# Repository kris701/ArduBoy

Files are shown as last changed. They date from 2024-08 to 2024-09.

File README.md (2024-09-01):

# ArduBoy

This is a project to make my own gameboy-like console, with its own scripting language and dynamic runtime on an Arduino.

Physically, its more or less equal to a Gameboy Pocket, except this one is a bit thicker and the screen is a bit smaller.
Other than that, it has the same button layout. 
Instead of using disposable batteries, it has a internal LiPo instead with a USB-C port for charging.
Games are semi-compiled into a easier to read format for the Arduino. The semi-compiled code is put on an SD card, that the ArduBoy can then parse and run.

In hindsight, it might have a bit of an overkill battery of 3000mAh, so it can technically run for a few days without a charge.

You can take a look in the [Games](./Games) folder for some already made games for the Arduino, or you can make some yourself!

You can use the CLI tool to compile the script file onto an SD card.
The tool will also do a bit of syntax checking to make sure there arent obvious errors in the script file.

## ArduBoy Script (`.abs`) Syntax

Generally the syntax of the ArduBoy Scripts are heavy encapsulation with `(` and `)`.
An example of this can be seen below:

```
(
	(:name Example)
	(:includes (:include core))

	(:func Setup
		(
			// Setup code goes here
			// This code only runs once
		)
	)

	(:func Loop
		(
			// Looping code goes here
			// The code in here will loop
		)
	)
)
```

## Parts

Here is a general list of the electronic parts that was used in this project.

* [3000 mAh battery](https://www.ebay.com/itm/121823784057)
* [USB-C Charging board](https://www.ebay.com/itm/325273541405)
* [SD card reader](https://www.ebay.com/itm/170895501953)
* [Arduino Nano](https://www.ebay.com/itm/364546971433?var=634055018693)
* [Button PCB](https://www.ebay.com/itm/296243650365?var=594299882127)
* [OLED Screen](https://www.ebay.com/itm/225810919466)
* [3.7v to 5v boster](https://www.ebay.com/itm/255301455926)

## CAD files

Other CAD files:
Fusion/ArduBoyBody.f3d

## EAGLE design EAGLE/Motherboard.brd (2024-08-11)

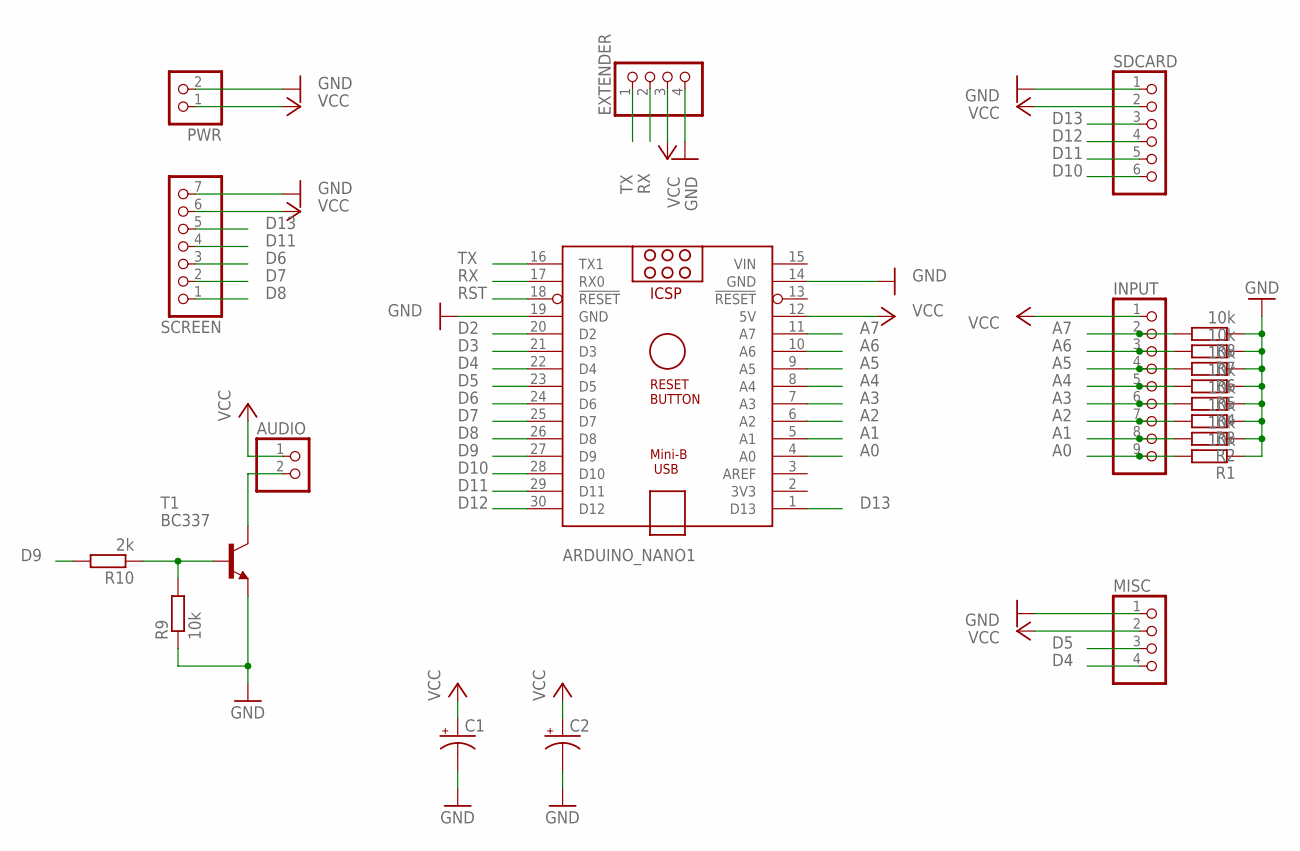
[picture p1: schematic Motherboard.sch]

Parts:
ARDUINO_NANO1: ARDUINO_NANO
AUDIO: PINHD-1X2; 1X02
C1, C2: CPOL-USE2.5-6; E2,5-6
EXTENDER: PINHD-1X4; 1X04
INPUT: PINHD-1X9; 1X09
MISC: PINHD-1X4; 1X04
PWR: PINHD-1X2; 1X02
R1, R2, R3, R4, R5, R6, R7, R8, R9: 10k; 0204/7
R10: 2k; 0204/7
SCREEN: PINHD-1X7; 1X07
SDCARD: PINHD-1X6; 1X06
T1: BC337; TO92

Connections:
A0: ARDUINO_NANO1.4 (A0), INPUT.9, R1.2
A1: ARDUINO_NANO1.5 (A1), INPUT.8, R2.2
A2: ARDUINO_NANO1.6 (A2), INPUT.7, R3.2
A3: ARDUINO_NANO1.7 (A3), INPUT.6, R4.2
A4: ARDUINO_NANO1.8 (A4), INPUT.5, R5.2
A5: ARDUINO_NANO1.9 (A5), INPUT.4, R6.2
A6: ARDUINO_NANO1.10 (A6), INPUT.3, R7.2
A7: ARDUINO_NANO1.11 (A7), INPUT.2, R8.2
D2: ARDUINO_NANO1.20 (D2)
D3: ARDUINO_NANO1.21 (D3)
D4: ARDUINO_NANO1.22 (D4), MISC.4
D5: ARDUINO_NANO1.23 (D5), MISC.3
D6: ARDUINO_NANO1.24 (D6), SCREEN.3
D7: ARDUINO_NANO1.25 (D7), SCREEN.2
D8: ARDUINO_NANO1.26 (D8), SCREEN.1
D9: ARDUINO_NANO1.27 (D9), R10.2
D10: ARDUINO_NANO1.28 (D10), SDCARD.6
D11: ARDUINO_NANO1.29 (D11), SCREEN.4, SDCARD.5
D12: ARDUINO_NANO1.30 (D12), SDCARD.4
D13: ARDUINO_NANO1.1 (D13), SCREEN.5, SDCARD.3
GND: ARDUINO_NANO1.14 (GND), ARDUINO_NANO1.19 (GND), C1.-, C2.-, EXTENDER.4, MISC.1, PWR.2, R1.1, R2.1, R3.1, R4.1, R5.1, R6.1, R7.1, R8.1, R9.1, SCREEN.7, SDCARD.1, T1.1 (E)
unnamed: AUDIO.2, T1.3 (C)
unnamed: R9.2, R10.1, T1.2 (B)
RST: ARDUINO_NANO1.18 (!RESET)
RX: ARDUINO_NANO1.17 (RX0), EXTENDER.2
TX: ARDUINO_NANO1.16 (TX1), EXTENDER.1
VCC: ARDUINO_NANO1.12 (5V), AUDIO.1, C1.+, C2.+, EXTENDER.3, INPUT.1, MISC.2, PWR.1, SCREEN.6, SDCARD.2
VIN: ARDUINO_NANO1.15 (VIN)

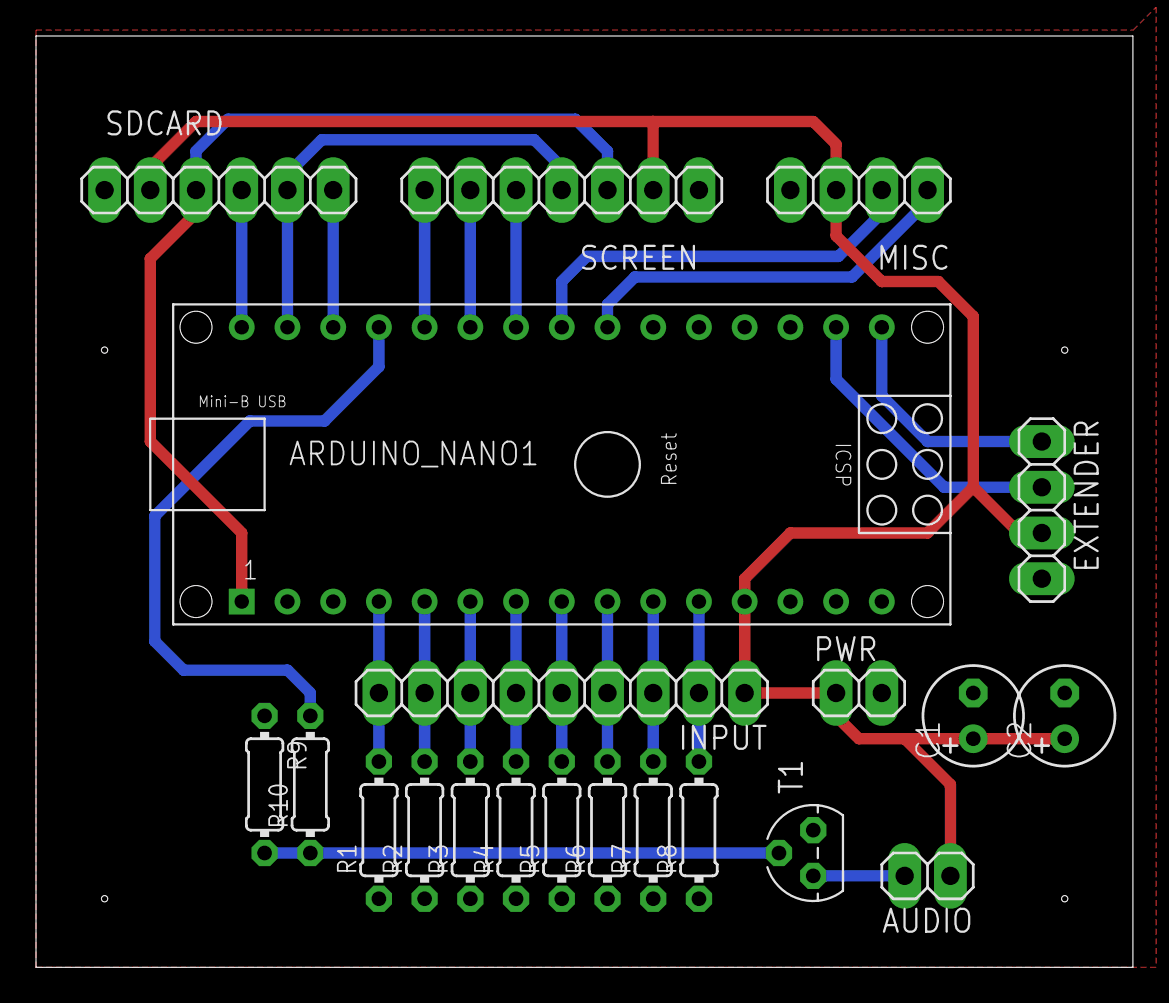
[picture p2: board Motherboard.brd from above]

Board: 2 copper layers, 60.9 x 51.7 mm, 21 parts (0 on the bottom side), 24 nets.

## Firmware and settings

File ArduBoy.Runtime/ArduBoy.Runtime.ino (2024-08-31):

#include <Adafruit_SSD1351.h>
#include <SPI.h>
#include <SD.h>

#define DEBUG

#define Audio_Pin               9
#define SD_CS                   10
#define SCREEN_CS               8
#define SCREEN_DC               7
#define SCREEN_RST              6
#define SCREEN_WIDTH            128
#define SCREEN_HEIGHT           128
#define INPUT_UP                A7
#define INPUT_DOWN              A4
#define INPUT_LEFT              A0
#define INPUT_RIGHT             A6
#define INPUT_A                 A2
#define INPUT_B                 A1
#define INPUT_SELECT            A5
#define INPUT_START             A3

#define BYTE_OFFSET             33
#define OP_FUNC_END             0 + BYTE_OFFSET
#define OP_CALL                 1 + BYTE_OFFSET
#define OP_IF                   2 + BYTE_OFFSET
#define OP_WAIT                 3 + BYTE_OFFSET
#define OP_SET                  4 + BYTE_OFFSET
#define OP_AUDIO                5 + BYTE_OFFSET
#define OP_DRAW_LINE            6 + BYTE_OFFSET
#define OP_GOTO                 7 + BYTE_OFFSET
#define OP_ADD                  8 + BYTE_OFFSET
#define OP_SUB                  9 + BYTE_OFFSET
#define OP_MULT                 10 + BYTE_OFFSET
#define OP_DIV                  11 + BYTE_OFFSET
#define OP_MOD                  12 + BYTE_OFFSET

#define OP_DRAW_CIRCLE          20 + BYTE_OFFSET
#define OP_DRAW_FILL_CIRCLE     21 + BYTE_OFFSET
#define OP_DRAW_TRIANGLE        22 + BYTE_OFFSET
#define OP_DRAW_FILL_TRIANGLE   23 + BYTE_OFFSET
#define OP_DRAW_RECTANGLE       24 + BYTE_OFFSET
#define OP_DRAW_FILL_RECTANGLE  25 + BYTE_OFFSET
#define OP_DRAW_TEXT            26 + BYTE_OFFSET
#define OP_DRAW_FILL            27 + BYTE_OFFSET

#define OP_IF_EQU               30 + BYTE_OFFSET
#define OP_IF_LES               31 + BYTE_OFFSET
#define OP_IF_LAR               32 + BYTE_OFFSET
#define OP_IF_NEQ               33 + BYTE_OFFSET

Adafruit_SSD1351 display = Adafruit_SSD1351(SCREEN_WIDTH, SCREEN_HEIGHT, &SPI, SCREEN_CS, SCREEN_DC, SCREEN_RST);
File gameFile;
int registers[32];
int stackPointers[32];
uint8_t currentStackPointer = 0;
enum mathExp {
    ADD, SUB,
    DIV, MUL,
    SET, MOD
};
const uint16_t  colors[8] = {
    0x0000, // BLACK
    0x001F, // BLUE
    0xF800, // RED
    0x07E0, // GREEN
    0x07FF, // CYAN
    0xF81F, // MAGENTA
    0xFFE0, // YELLOW
    0xFFFF, // WHITE
};
uint8_t inputBuffer[10];

void setup() {
#if defined(DEBUG)
    Serial.begin(115200);
#endif

    display.begin();
    display.fillScreen(colors[0]);
    display.setTextSize(2);
    display.setTextColor(colors[7]);

    for (int i = -20; i < 60; i += 3) {
        display.fillRect(0, i - 5, SCREEN_WIDTH, 16, colors[0]);
        display.setCursor(25, i);
        display.print(F("ArduBoy"));
        delay(25);
    }
    display.setTextSize(1);

    delay(1000);

    //pinMode(INPUT_UP, INPUT);
    pinMode(INPUT_DOWN, INPUT);
    pinMode(INPUT_LEFT, INPUT);
    pinMode(INPUT_RIGHT, INPUT);
    pinMode(INPUT_A, INPUT);
    pinMode(INPUT_B, INPUT);
    pinMode(INPUT_SELECT, INPUT);
    pinMode(INPUT_START, INPUT);

    if (!SD.begin(SD_CS) || !SD.exists(F("game.bin"))) {
        while (1) { 
#if defined(DEBUG)
            Serial.println(F("Game file not found"));
#endif
            delay(1000); 
        };
    }

    gameFile = SD.open(F("game.bin"), FILE_READ);
    display.fillScreen(colors[0]);
}

void loop() {
    while (gameFile.available()) {
        String line = gameFile.readStringUntil('\n');
        if (line == "")
            continue;
        SplitString(&line);
        int target = line.charAt(0);
        switch (target)
        {
        case OP_CALL: DoCall(&line); break;
        case OP_IF: DoIf(&line); break;
        case OP_WAIT: DoWait(&line); break;
        case OP_SET: DoMathExp(&line, mathExp::SET); break;
        case OP_ADD: DoMathExp(&line, mathExp::ADD); break;
        case OP_SUB: DoMathExp(&line, mathExp::SUB); break;
        case OP_MULT: DoMathExp(&line, mathExp::MUL); break;
        case OP_DIV: DoMathExp(&line, mathExp::DIV); break;
        case OP_MOD: DoMathExp(&line, mathExp::MOD); break;
        case OP_AUDIO: DoAudio(&line); break;
        case OP_DRAW_LINE: DoDrawLine(&line); break;
        case OP_DRAW_CIRCLE: DoDrawCircle(&line, false); break;
        case OP_DRAW_FILL_CIRCLE: DoDrawCircle(&line, true); break;
        case OP_DRAW_TRIANGLE: DoDrawTriangle(&line, false); break;
        case OP_DRAW_FILL_TRIANGLE: DoDrawTriangle(&line, true); break;
        case OP_DRAW_RECTANGLE: DoDrawRectangle(&line, false); break;
        case OP_DRAW_FILL_RECTANGLE: DoDrawRectangle(&line, true); break;
        case OP_DRAW_TEXT: DoDrawText(&line); break;
        case OP_DRAW_FILL: DoDrawFill(&line); break;
        case OP_GOTO: DoGoto(&line); break;
        case OP_FUNC_END: 
            currentStackPointer--;
            gameFile.seek(stackPointers[currentStackPointer]); break;
        default:
            break;
        }
    }
}

int GetValueAsInt(const char* str, uint8_t from)
{
    if (str[from] == '%')
        return registers[atoi(str + from + 1)];
    if (str[from] == '|')
        return GetReservedValue(atoi(str + from + 1));
    return atoi(str + from);
}

String GetValueAsStr(String* str) {
    if (str->startsWith(F("%")) || str->startsWith(F("|")))
        return String(GetValueAsInt(str->c_str(), 0));
    return *str;
}

int GetReservedValue(int target) {
    switch (target) {
        // Input
                // Needed since A6 and A7 cannot work as digital pins
    case 0: return analogRead(INPUT_UP) > 512;
    case 1: return digitalRead(INPUT_DOWN);
    case 2: return digitalRead(INPUT_LEFT);
                // Needed since A6 and A7 cannot work as digital pins
    case 3: return analogRead(INPUT_RIGHT) > 512;
    case 4: return digitalRead(INPUT_A);
    case 5: return digitalRead(INPUT_B);
    case 6: return digitalRead(INPUT_SELECT);
    case 7: return digitalRead(INPUT_START);
        // Misc
    case 8: return millis();
    }
    return -1;
}

void SplitString(String* str) {
    inputBuffer[0] = str->indexOf(' ') + 1;
    uint8_t offset = inputBuffer[0];
    uint8_t index = 1;
    while (offset != 255) {
        offset = str->indexOf(' ', offset + 1);
        if (offset != 255)
            inputBuffer[index++] = offset + 1;
    }
}

#pragma region Actions

void DoCall(String* str) {
    int pos = GetValueAsInt(str->c_str(), 2);
    stackPointers[currentStackPointer++] = gameFile.position();
    gameFile.seek(pos - 1);
}

void DoIf(String* str) {
    int skip = GetValueAsInt(str->c_str(), inputBuffer[0]);
    int left = GetValueAsInt(str->c_str(), inputBuffer[1]);
    String opStr = str->substring(inputBuffer[2], inputBuffer[3]);
    opStr.trim();
    char op = opStr.charAt(0);
    int right = GetValueAsInt(str->c_str(), inputBuffer[3]);

    bool result = false;
    switch (op)
    {
    case OP_IF_EQU: result = left == right; break;
    case OP_IF_LAR: result = left > right; break;
    case OP_IF_LES: result = left < right; break;
    case OP_IF_NEQ: result = left != right; break;
    default:
        break;
    }

    if (!result)
        gameFile.seek(skip - 1);
}

void DoWait(String* str) {
    int time = GetValueAsInt(str->c_str(), 2);
    delay(time);
}

void DoMathExp(String* str, mathExp type) {
    int index = GetValueAsInt(str->c_str(), inputBuffer[0]);
    int value = GetValueAsInt(str->c_str(), inputBuffer[1]);
    switch (type)
    {
    case ADD: registers[index] += value; break;
    case SUB: registers[index] -= value; break;
    case DIV: registers[index] /= value; break;
    case MUL: registers[index] *= value; break;
    case SET: registers[index] = value; break;
    case MOD: registers[index] %= value; break;
    default:
        break;
    }
}

void DoAudio(String* str) {
    int value = GetValueAsInt(str->c_str(), 2);
    tone(Audio_Pin, value);
}

void DoDrawLine(String* str) {
    int x1 = GetValueAsInt(str->c_str(), inputBuffer[0]);
    int y1 = GetValueAsInt(str->c_str(), inputBuffer[1]);
    int x2 = GetValueAsInt(str->c_str(), inputBuffer[2]);
    int y2 = GetValueAsInt(str->c_str(), inputBuffer[3]);
    int color = colors[GetValueAsInt(str->c_str(), inputBuffer[4])];

    display.drawLine(x1, y1, x2, y2, color);
}

void DoDrawCircle(String* str, bool fill) {
    int x = GetValueAsInt(str->c_str(), inputBuffer[0]);
    int y = GetValueAsInt(str->c_str(), inputBuffer[1]);
    int radius = GetValueAsInt(str->c_str(), inputBuffer[2]);
    int color = colors[GetValueAsInt(str->c_str(), inputBuffer[3])];
    if (fill)
        display.fillCircle(x, y, radius, color);
    else
        display.drawCircle(x, y, radius, color);
}

void DoDrawTriangle(String* str, bool fill) {
    int x1 = GetValueAsInt(str->c_str(), inputBuffer[0]);
    int y1 = GetValueAsInt(str->c_str(), inputBuffer[1]);
    int x2 = GetValueAsInt(str->c_str(), inputBuffer[2]);
    int y2 = GetValueAsInt(str->c_str(), inputBuffer[3]);
    int x3 = GetValueAsInt(str->c_str(), inputBuffer[4]);
    int y3 = GetValueAsInt(str->c_str(), inputBuffer[5]);
    int color = colors[GetValueAsInt(str->c_str(), inputBuffer[6])];
    if (fill)
        display.fillTriangle(x1, y1, x2, y2, x3, y3, color);
    else
        display.drawTriangle(x1, y1, x2, y2, x3, y3, color);
}

void DoDrawRectangle(String* str, bool fill) {
    int x = GetValueAsInt(str->c_str(), inputBuffer[0]);
    int y = GetValueAsInt(str->c_str(), inputBuffer[1]);
    int width = GetValueAsInt(str->c_str(), inputBuffer[2]);
    int heigth = GetValueAsInt(str->c_str(), inputBuffer[3]);
    int color = colors[GetValueAsInt(str->c_str(), inputBuffer[4])];
    if (fill)
        display.fillRect(x, y, width, heigth, color);
    else
        display.drawRect(x, y, width, heigth, color);
}

void DoDrawText(String* str) {
    int x = GetValueAsInt(str->c_str(), inputBuffer[0]);
    int y = GetValueAsInt(str->c_str(), inputBuffer[1]);
    int size = GetValueAsInt(str->c_str(), inputBuffer[2]);
    int color = colors[GetValueAsInt(str->c_str(), inputBuffer[3])];
    String text = GetValueAsStr(&str->substring(inputBuffer[4]));

    display.setTextColor(color);
    display.setTextSize(size);
    display.setCursor(x, y);
    display.print(text);
}

void DoDrawFill(String* str) {
    display.fillScreen(colors[GetValueAsInt(str->c_str(), 2)]);
}

void DoGoto(String* str) {
    int index = GetValueAsInt(str->c_str(), 2);
    gameFile.seek(index - 1);
}

#pragma endregion

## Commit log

2024-06-27 Initial setup for the Arduino side
2024-07-01 * Added mathmatical expressions (+,-,* and /) * Made so that the jmp codes are in characters instead of lines (the Arduino side needs it to be characters) * Refactoring of the initial Arduino code
2024-07-01 Bytecode fixes for the opcodes
    [ArduBoy.Runtime.ino]
2024-07-07 added initial EAGLE files
    [Motherboard.brd, Motherboard.sch]
2024-07-08 Updated EAGLE schematics and board
    [Motherboard.brd, Motherboard.sch]
2024-07-24 Updated motherboard schetch and board design
    [Motherboard.brd, Motherboard.sch]
2024-07-24 Set ports correctly in the code
    [ArduBoy.Runtime.ino]
2024-07-24 * Redid the board design * Repinned a lot
    [Motherboard.brd, Motherboard.sch]
2024-07-25 Added boarder drill holes to the pcb board design
    [Motherboard.brd]
2024-08-11 Got the basic arduino stuff to work
    [Motherboard.brd]
2024-08-11 Lots of fixes and optimisations
    [ArduBoy.Runtime.ino]
2024-08-11 Fixed the line system for if statements
    [ArduBoy.Runtime.ino]
2024-08-12 Fixed bad stack pointer size
    [ArduBoy.Runtime.ino]
2024-08-12 Fixed a bug on the runtime, where the first value in a string was offset wrong
    [ArduBoy.Runtime.ino]
2024-08-15 * Added some initial documentation * Added the current fusion design file
    [ArduBoyBody.f3d]
2024-08-31 Audio test and button mapping
2024-09-01 * Cleanup * Better readme * Updated fusion drawing
    [ArduBoyBody.f3d]
